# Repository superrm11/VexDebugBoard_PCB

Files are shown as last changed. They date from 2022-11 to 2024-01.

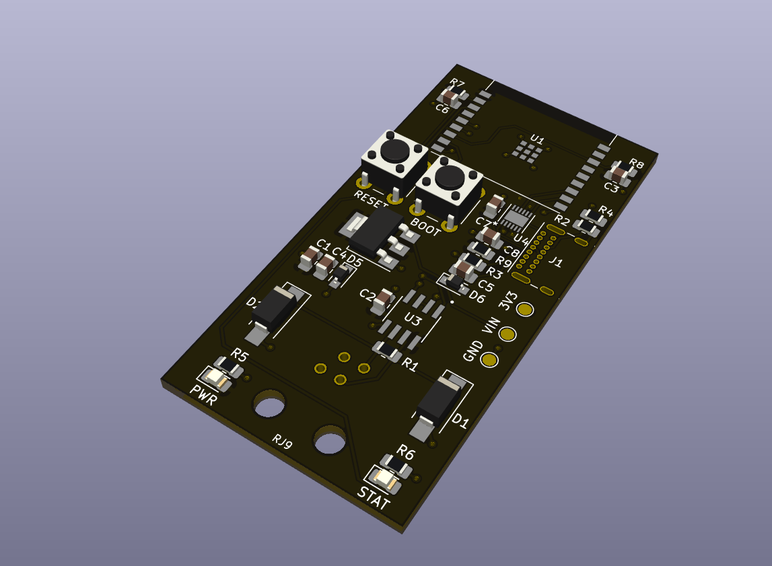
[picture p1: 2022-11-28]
Pictures/Rev2.1_render_top.png

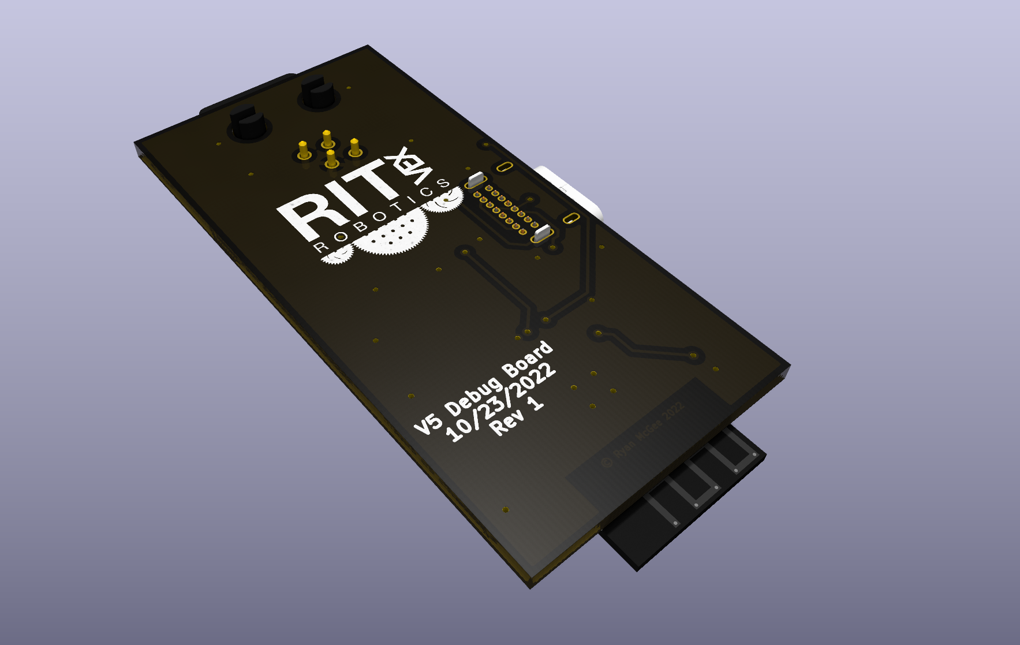
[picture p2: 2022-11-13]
Pictures/Screenshot_20221023_162542.png

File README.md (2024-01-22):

# _VexDebugBoard PCB_

This is the main hardware repository for the V5 Debug Board: a board designed to slot into the VEX V5 Smart Port, 
and transmit debug data over a websocket to a laptop. The data is received by a [Foxglove application](https://foxglove.dev) instance or ROS RViz, and allows for:

- 3D visualization of Odometry
- Real-time graphing for robot tuning
- Wireless print statements

This repository contains the circuit diagram, BOM and PCB layout for the board. 

## Pinout
Smart Port RX (from Brain): GPIO7  
Smart Port TX (to Brain): GPIO6  
RS485 Mode (TX=ON, RX=OFF): GPIO10  
STAT LED: GPIO4  
DBG_LED: GPIO18  
SD SPI MISO: GPIO0  
SD SPI MOSI: GPIO1  
SD SPI CS: GPIO3  
SD SPI SCL: GPIO19  

## Image Library
Rev3 0_render_top
Rev3 0_render_bottom
rev3 0_schematic
rev3 0_layout

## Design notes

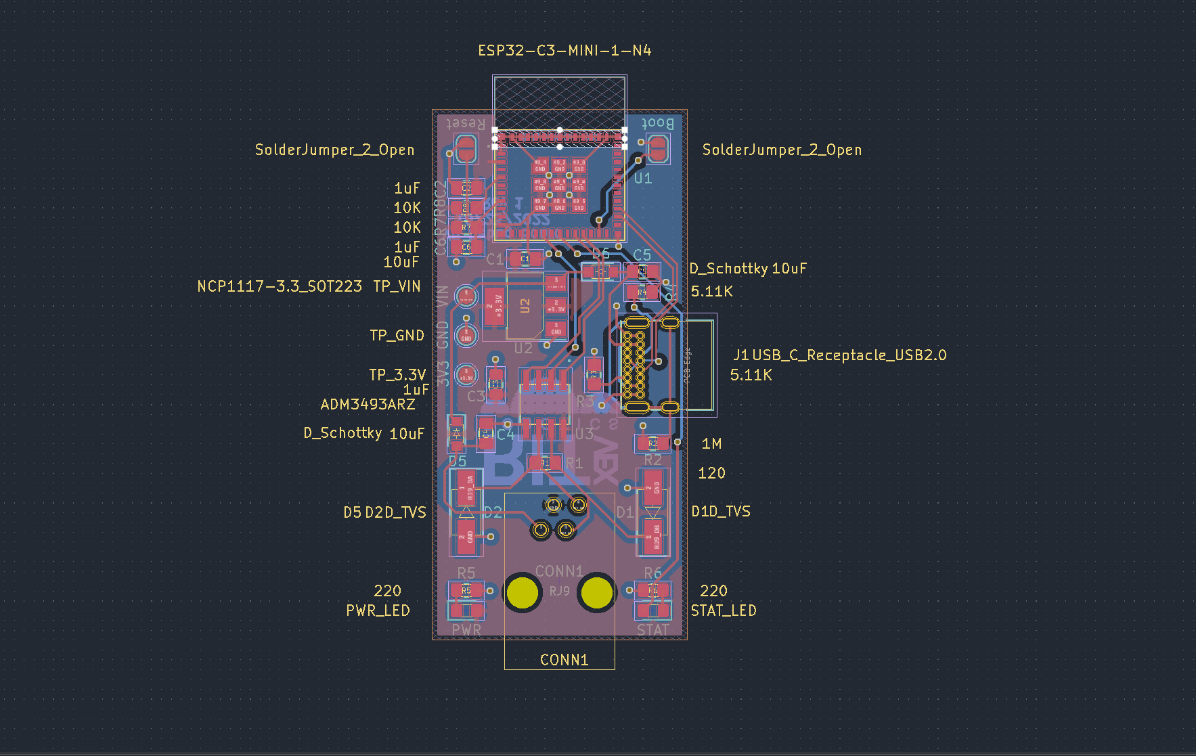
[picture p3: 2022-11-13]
Pictures/Screenshot_20221023_162637.png

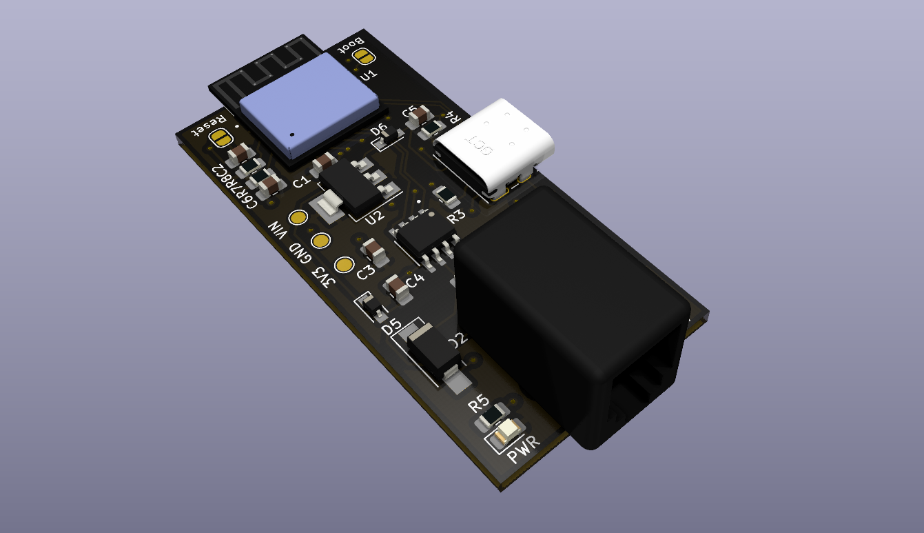
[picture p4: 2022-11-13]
Pictures/Screenshot_20221023_162415.png

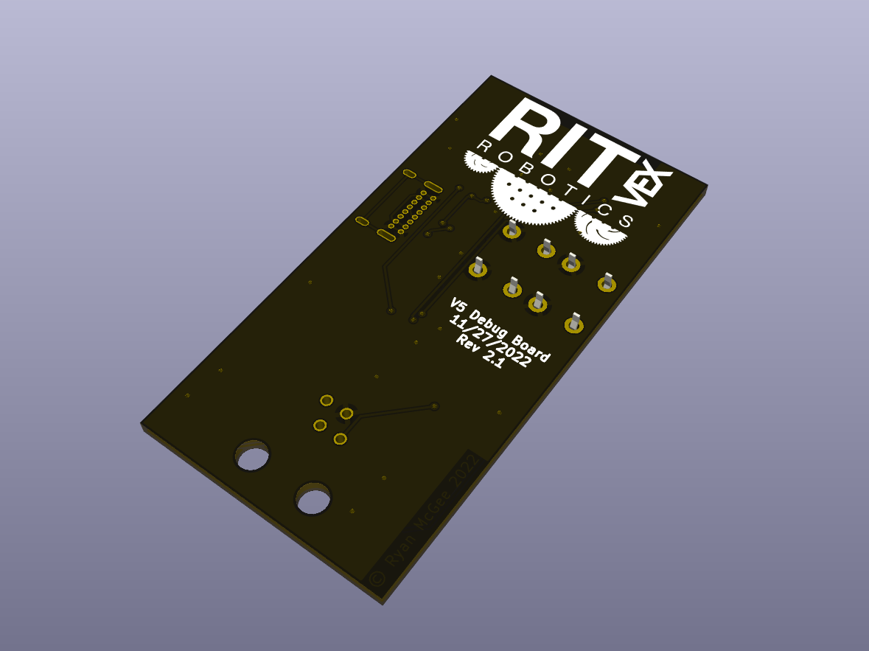
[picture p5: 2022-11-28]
Pictures/Rev2.1_render_bottom.png

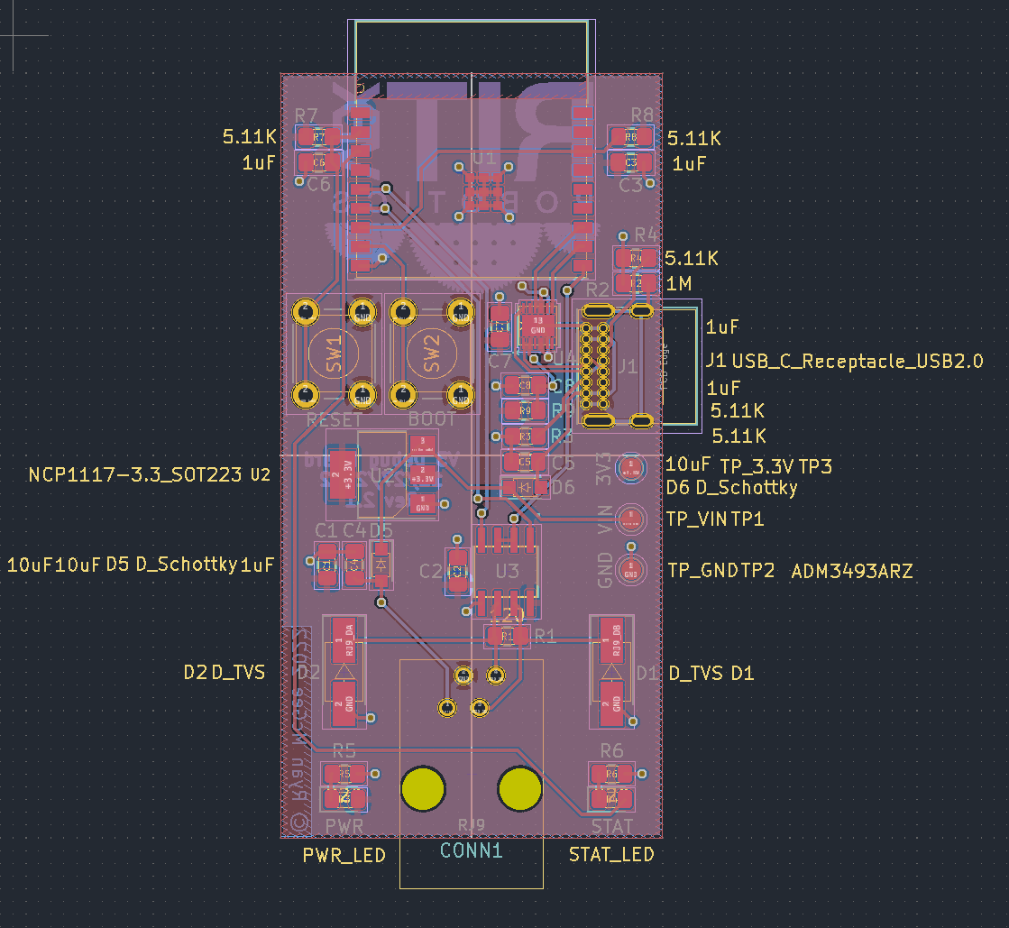
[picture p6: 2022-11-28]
Pictures/Rev2.1.png

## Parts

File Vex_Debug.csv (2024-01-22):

# | Reference | Qty | Value | Footprint | DNP | Stock | To Buy | # of boards
2 | C1, C4, C5 | 3 | 10uF | Capacitor_SMD:C_0805_2012Metric_Pad1.18x1.45mm_HandSolder |  | 7 | 2 | 3
3 | C2, C3, C6, C7 | 4 | 1uF | Capacitor_SMD:C_0805_2012Metric_Pad1.18x1.45mm_HandSolder |  | 13 | 0
4 | CONN1 | 1 | RJ9 | RJ9:RJ9_Jack |  | 3 | 0
5 | D1, D2 | 2 | D_TVS | Diode_SMD:D_SMA_Handsoldering |  | 6 | 0
6 | D3 | 1 | PWR_LED | LED_SMD:LED_0805_2012Metric_Pad1.15x1.40mm_HandSolder |  | 14 | 0
7 | D4 | 1 | STAT_LED | LED_SMD:LED_0805_2012Metric_Pad1.15x1.40mm_HandSolder |  |  | 0
8 | D5, D6 | 2 | D_Schottky | Diode_SMD:D_SOD-323_HandSoldering |  | 6 | 0
9 | D7 | 1 | DBG_LED | LED_SMD:LED_0805_2012Metric_Pad1.15x1.40mm_HandSolder |  | 0 | 0
11 | J1 | 1 | USB_C_Receptacle_USB2.0 | Connector_USB:USB_C_Receptacle_GCT_USB4085 |  | 3 | 0
12 | J2 | 1 | Micro_SD_Card | Connector_Card:microSD_HC_Molex_47219-2001 |  | 0 | 3
13 | J3 | 1 | Conn_01x02_Pin | Connector_PinHeader_2.54mm:PinHeader_1x02_P2.54mm_Vertical |  | X | X
14 | Q1, Q2 | 2 | BC817 | Package_TO_SOT_SMD:SOT-23 |  |  | 6
15 | R1 | 1 | 120 | Resistor_SMD:R_0805_2012Metric_Pad1.20x1.40mm_HandSolder |  | 17 | 0
16 | R2, R13 | 2 | 1M | Resistor_SMD:R_0805_2012Metric_Pad1.20x1.40mm_HandSolder |  | 17 | 0
17 | R3, R4, R7, R8, R10, R11, R12 | 7 | 5.11K | Resistor_SMD:R_0805_2012Metric_Pad1.20x1.40mm_HandSolder |  | 26 | 0
18 | R5, R6, R9 | 3 | 220 | Resistor_SMD:R_0805_2012Metric_Pad1.20x1.40mm_HandSolder |  | 14 | 0
19 | U1 | 1 | ESP32-C3-WROOM-02-N4 | ESP32-C3-WROOM:ESP32-C3-WROOM-02-N4 |  | 3 | 0
20 | U2 | 1 | NCP1117-3.3_SOT223 | Package_TO_SOT_SMD:SOT-223-3_TabPin2 |  | 3 | 0
21 | U3 | 1 | ADM3493ARZ | RS485_tran:SOIC127P600X175-8N |  | 3 | 0
22 | U4 | 1 | FT231XQ | Package_DFN_QFN:QFN-20-1EP_4x4mm_P0.5mm_EP2.5x2.5mm |  | 0 | 3

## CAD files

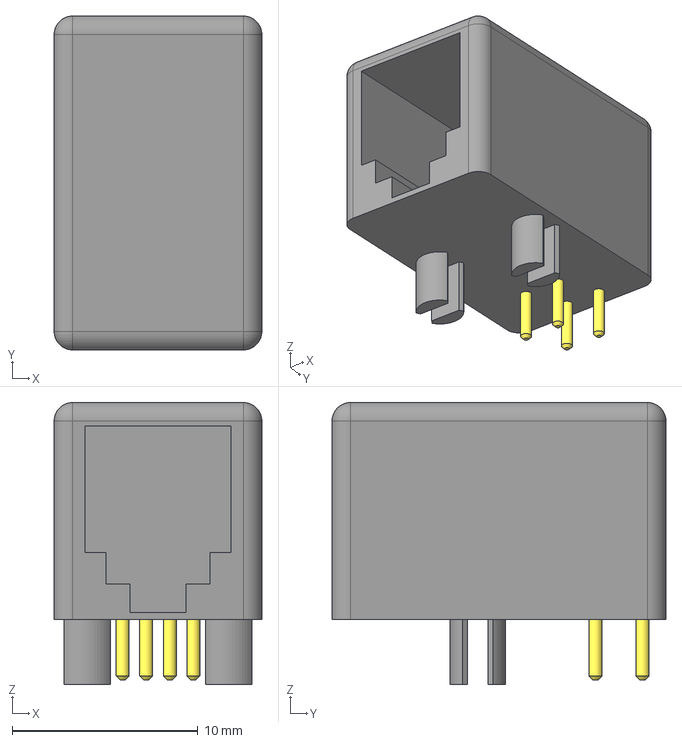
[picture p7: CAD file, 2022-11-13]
FreeCAD/RJ9_Jack_Footprint-A-2004-3-4-LP-N-R001.step
11.2 x 18.0 x 15.2 mm

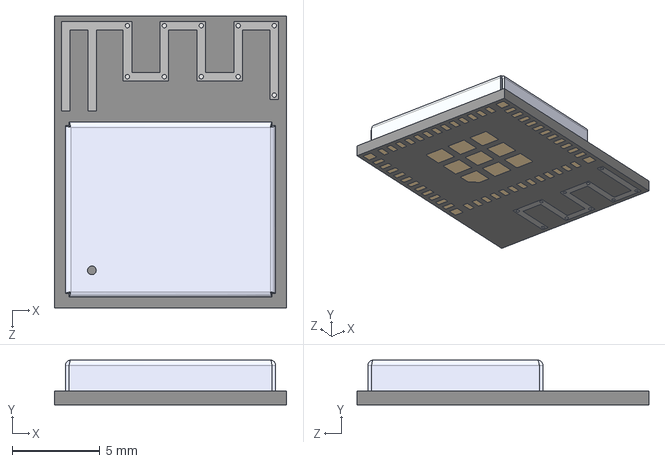
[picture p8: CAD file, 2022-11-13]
Parts/ESP32-C3-MINI/ESP32-C3-MINI-1-N4.step
13.2 x 2.55 x 16.6 mm

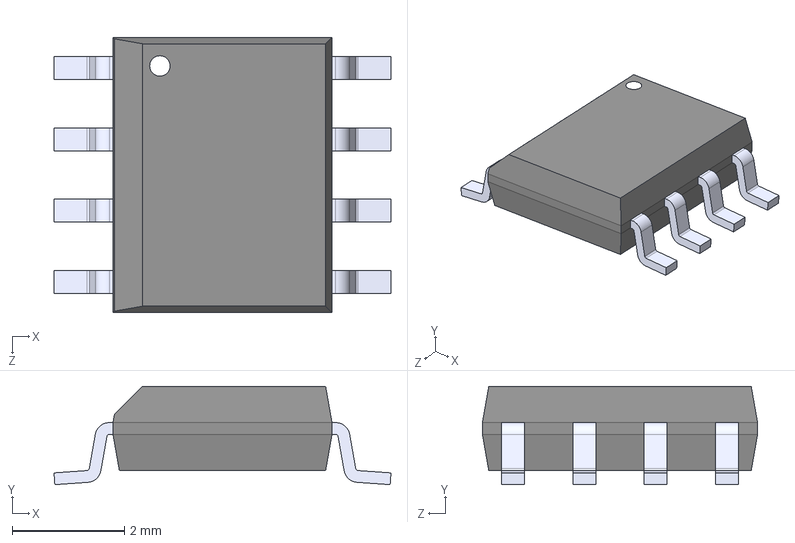
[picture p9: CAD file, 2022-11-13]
Parts/RS485_tran/ADM3493ARZ.step
6.00 x 1.75 x 4.90 mm

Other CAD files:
Parts/RJ9/RJ9_Jack_Footprint-A-2004-3-4-LP-N-R001.step
FreeCAD/RJ9_Jack_Footprint.FCStd

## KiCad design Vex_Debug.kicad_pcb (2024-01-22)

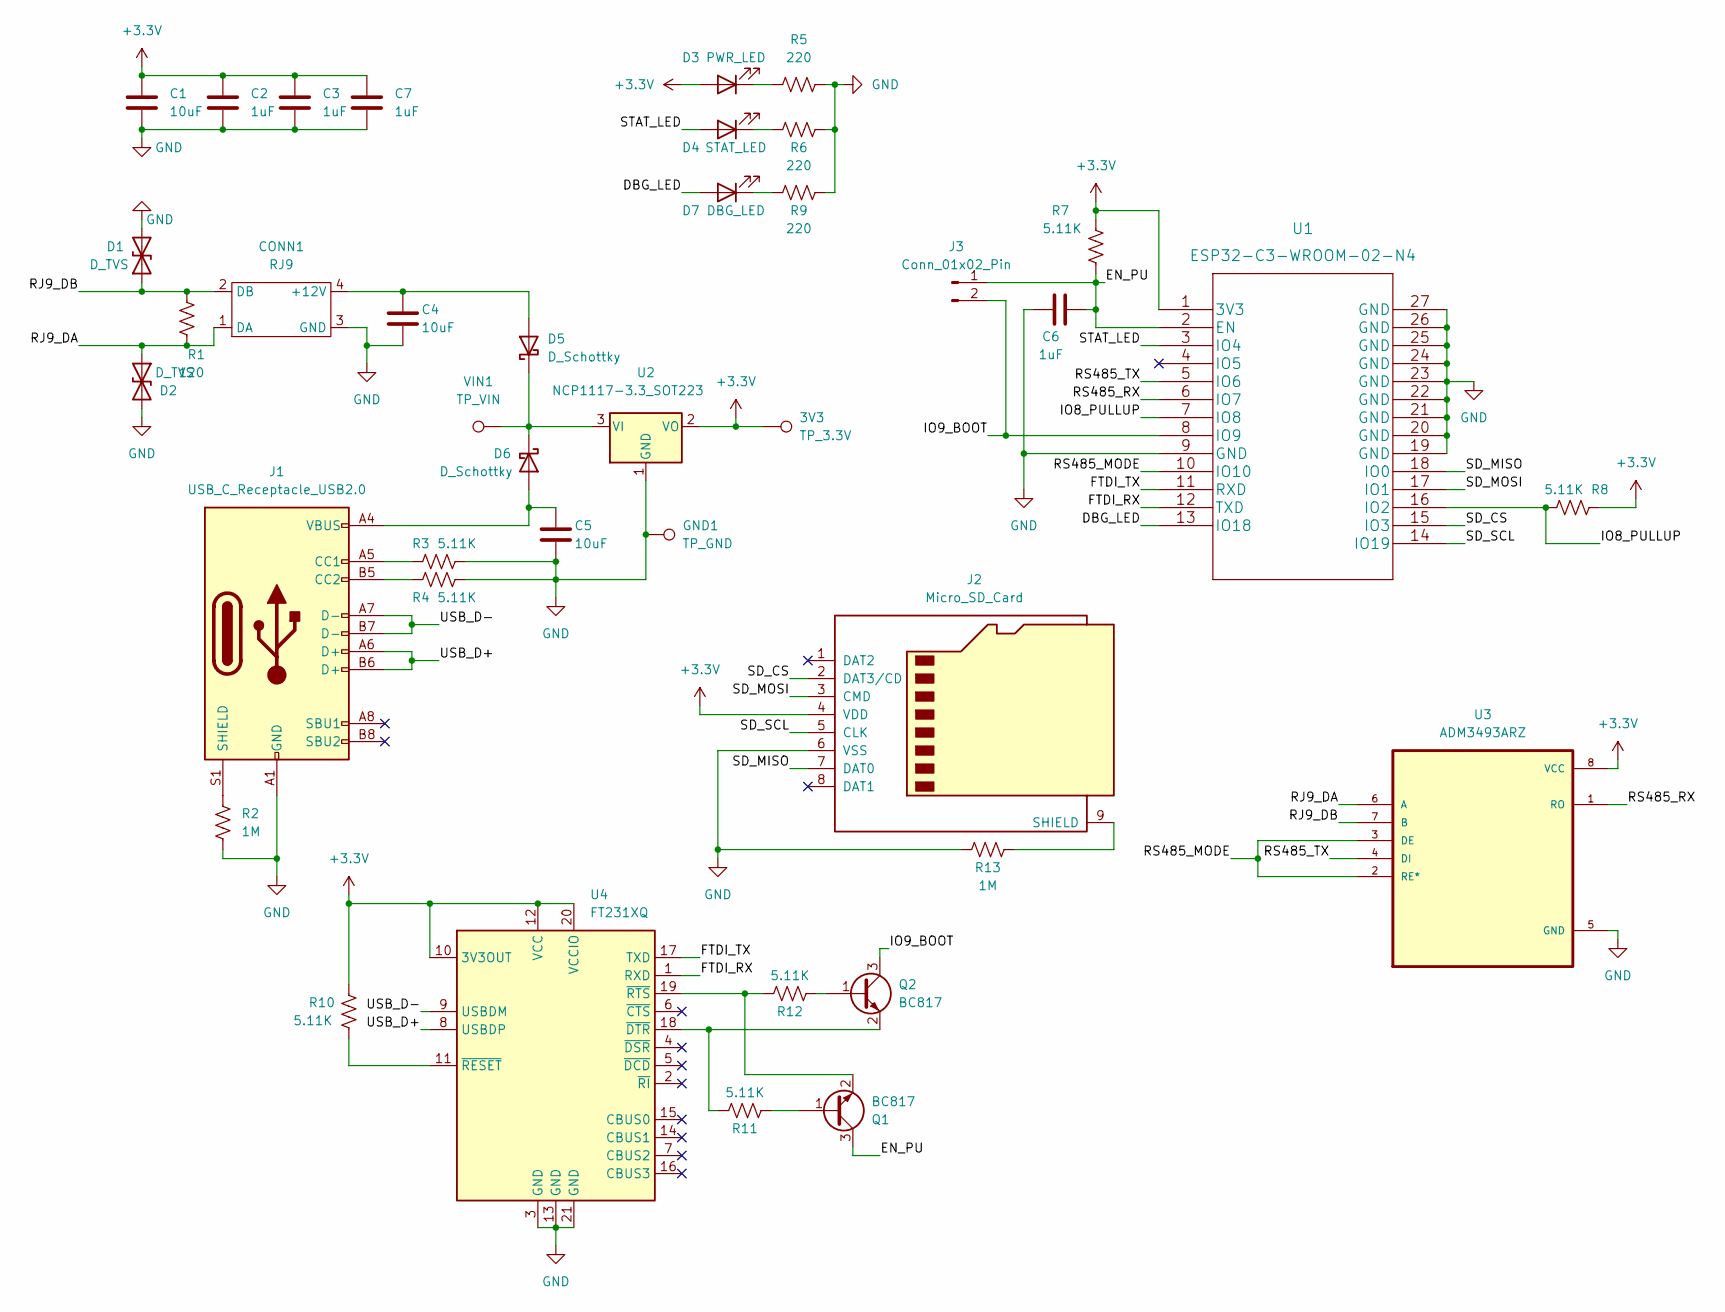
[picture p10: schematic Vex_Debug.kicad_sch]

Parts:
3V3: TP_3.3V; TestPoint_Pad_D1.5mm
C1, C4, C5: 10uF; C_0805_2012Metric_Pad1.18x1.45mm_HandSolder
C2, C3, C6, C7: 1uF; C_0805_2012Metric_Pad1.18x1.45mm_HandSolder
CONN1: RJ9; RJ9_Jack
D1, D2: D_TVS; D_SMA_Handsoldering
D3: PWR_LED; LED_0805_2012Metric_Pad1.15x1.40mm_HandSolder
D4: STAT_LED; LED_0805_2012Metric_Pad1.15x1.40mm_HandSolder
D5, D6: D_Schottky; D_SOD-323_HandSoldering
D7: DBG_LED; LED_0805_2012Metric_Pad1.15x1.40mm_HandSolder
GND1: TP_GND; TestPoint_Pad_D1.5mm
J1: USB_C_Receptacle_USB2.0; USB_C_Receptacle_GCT_USB4085
J2: Micro_SD_Card; microSD_HC_Molex_47219-2001
J3: Conn_01x02_Pin; PinHeader_1x02_P2.54mm_Vertical
Q1, Q2: BC817; SOT-23
R1: 120; R_0805_2012Metric_Pad1.20x1.40mm_HandSolder
R2, R13: 1M; R_0805_2012Metric_Pad1.20x1.40mm_HandSolder
R3, R4, R7, R8, R10, R11, R12: 5.11K; R_0805_2012Metric_Pad1.20x1.40mm_HandSolder
R5, R6, R9: 220; R_0805_2012Metric_Pad1.20x1.40mm_HandSolder
U1: ESP32-C3-WROOM-02-N4
U2: NCP1117-3.3_SOT223; SOT-223-3_TabPin2
U3: ADM3493ARZ; SOIC127P600X175-8N
U4: FT231XQ; QFN-20-1EP_4x4mm_P0.5mm_EP2.5x2.5mm
VIN1: TP_VIN; TestPoint_Pad_D1.5mm

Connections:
+3.3V: 3V3.1, C1.1, C2.1, C3.1, C7.1, D3.2 (A), J2.4 (VDD), R7.2, R8.2, R10.2, U1.1 (3V3), U2.2 (VO), U3.8 (VCC), U4.10 (3V3OUT), U4.12 (VCC), U4.20 (VCCIO)
/DBG_LED: D7.2 (A), U1.13 (IO18)
/EN_PU: C6.1, J3.1, Q1.3 (C), R7.1, U1.2 (EN)
/FTDI_RX: U1.12 (TXD), U4.1 (RXD)
/FTDI_TX: U1.11 (RXD), U4.17 (TXD)
/IO8_PULLUP: R8.1, U1.7 (IO8), U1.16 (IO2)
/IO9_BOOT: J3.2, Q2.3 (C), U1.8 (IO9)
/RJ9_DA: CONN1.1 (DA), D2.1 (A1), R1.2, U3.6 (A)
/RJ9_DB: CONN1.2 (DB), D1.1 (A1), R1.1, U3.7 (B)
/RS485_MODE: U1.10 (IO10), U3.2 (RE*), U3.3 (DE)
/RS485_RX: U1.6 (IO7), U3.1 (RO)
/RS485_TX: U1.5 (IO6), U3.4 (DI)
/SD_CS: J2.2 (DAT3/CD), U1.15 (IO3)
/SD_MISO: J2.7 (DAT0), U1.18 (IO0)
/SD_MOSI: J2.3 (CMD), U1.17 (IO1)
/SD_SCL: J2.5 (CLK), U1.14 (IO19)
/STAT_LED: D4.2 (A), U1.3 (IO4)
/USB_D+: J1.A6 (D+), J1.B6 (D+), U4.8 (USBDP)
/USB_D-: J1.A7 (D-), J1.B7 (D-), U4.9 (USBDM)
GND: C1.2, C2.2, C3.2, C4.2, C5.2, C6.2, C7.2, CONN1.3 (GND), D1.2 (A2), D2.2 (A2), GND1.1, J1.A1 (GND), J1.A12 (GND), J1.B1 (GND), J1.B12 (GND), J2.6 (VSS), R2.2, R3.2, R4.2, R5.2, R6.2, R9.2, R13.2, U1.9 (GND), U1.19 (GND), U1.20 (GND), U1.21 (GND), U1.22 (GND), U1.23 (GND), U1.24 (GND), U1.25 (GND), U1.26 (GND), U1.27 (GND), U2.1 (GND), U3.5 (GND), U4.3 (GND), U4.13 (GND), U4.21 (GND); also elsewhere on the board
unnamed: C4.1, CONN1.4 (+12V), D5.2 (A)
unnamed: D3.1 (K), R5.1
unnamed: D4.1 (K), R6.1
unnamed 23: D5.1 (K), D6.1 (K), U2.3 (VI), VIN1.1; also elsewhere on the board
unnamed: C5.1, D6.2 (A), J1.A4 (VBUS), J1.A9 (VBUS), J1.B4 (VBUS), J1.B9 (VBUS)
unnamed: D7.1 (K), R9.1
unnamed: J1.A5 (CC1), R3.1
unnamed: J1.B5 (CC2), R4.1
unnamed: J1.S1 (SHIELD), R2.1
unnamed: J2.9 (SHIELD), R13.1
unnamed: Q1.1 (B), R11.2
unnamed: Q1.2 (E), R12.1, U4.19 (~RTS)
unnamed: Q2.1 (B), R12.2
unnamed: Q2.2 (E), R11.1, U4.18 (~DTR)
unnamed: R10.1, U4.11 (~RESET)

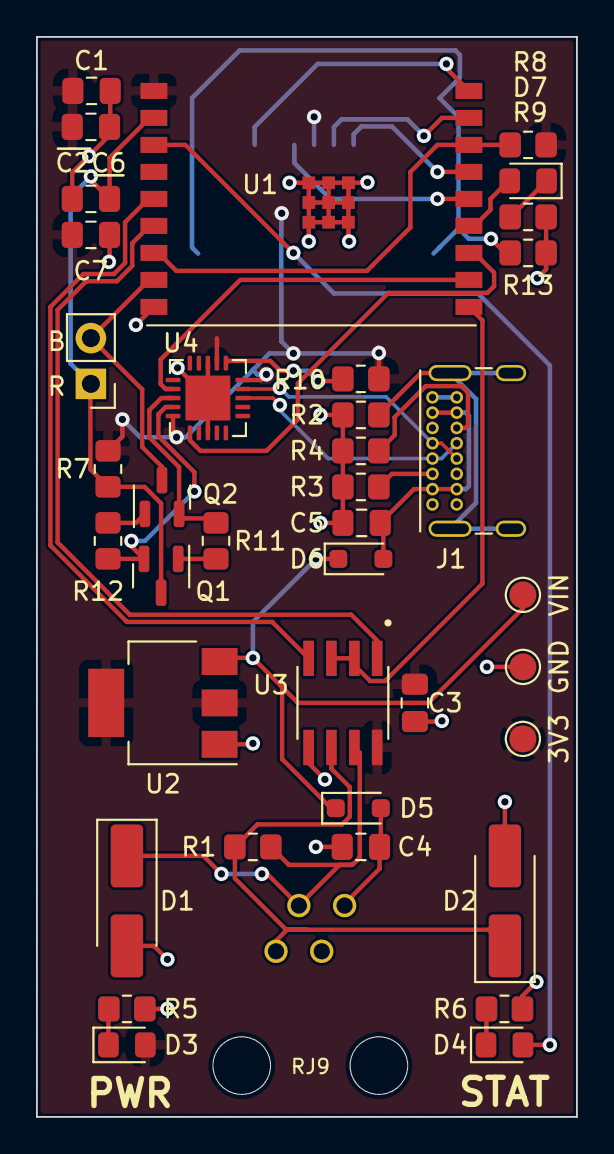
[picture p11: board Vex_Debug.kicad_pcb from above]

Board: 2 copper layers, 30.0 x 60.0 mm, 40 parts (1 on the bottom side), 35 nets.

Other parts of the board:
GND: TP_GND; TestPoint_Pad_D1.5mm
VIN: TP_VIN; TestPoint_Pad_D1.5mm

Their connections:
GND: GND.1; also elsewhere on the board
unnamed 23: VIN.1; also elsewhere on the board

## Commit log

2022-11-13 Revision 1 (ESP32-C3-MINI)
    [ADM3493ARZ.step, ESP32-C3-MINI-1-N4.step, RJ9_Jack_Footprint-A-2004-3-4-LP-N-R001.step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]
2022-11-28 Revision 2.1 release
    [Vex_Debug-B_Cu.gbr, Vex_Debug-B_Mask.gbr, Vex_Debug-B_Paste.gbr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]
2024-01-22 Updated to revision 3.0
    [Vex_Debug-B_Cu.gbr, Vex_Debug-B_Mask.gbr, Vex_Debug-B_Paste.gbr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]

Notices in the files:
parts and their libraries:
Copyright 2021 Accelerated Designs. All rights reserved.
